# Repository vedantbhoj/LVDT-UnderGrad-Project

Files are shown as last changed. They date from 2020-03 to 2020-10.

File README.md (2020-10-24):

# LVDT-UnderGrad-Project
LVDT(Linear Variable Diffrential Transformer)

Please check out the working of this project on YouTube.

<a href="https://youtu.be/okFGslv-gCQ">Demo - Youtube Video</a>

<a href="https://github.com/vedantbhoj/LVDT-UnderGrad-Project/blob/master/PROJECT%20REPORT/PROJECT%20REPORT.pdf">Project Report</a>

Note: Cannot support this repository anymore. Thanks!!

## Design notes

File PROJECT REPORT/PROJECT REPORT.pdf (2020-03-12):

## 1.INTRODUCTION

“LVDT”

LVDT is most widely used inductive transducer for translating the linear motion into

electrical signal. Magnetic coupling between primary and secondary coils is established by

using a soft and movable iron core. In normal LVDT both the secondary coils are connected

in series opposition. However, the output voltage is zero. As the core moves up or down, the

induced voltage in one secondary coil increases while that of the other decreases. Here the

magnitude of the output voltage is in AC nature.

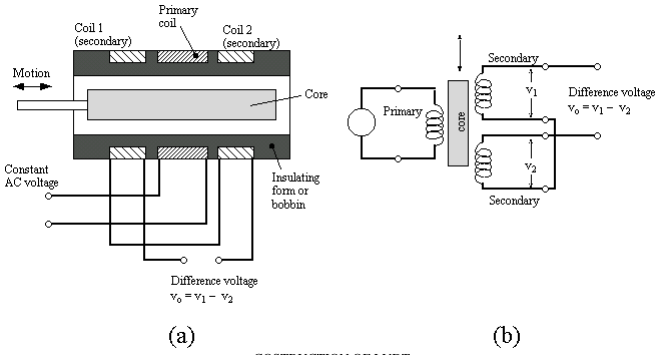
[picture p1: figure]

COSTRUCTION OF LVDT

## 2. BACKGROUND

Since the 1930s, linear variable differential transformers (LVDTs) have found widespread

application in industry for the measurement of displacement. Early development was driven by the

needs of the chemical industry to remotely measure process variables, and during World War II

development accelerated rapidly as the LVDT found use in aircraft and weapon systems. Today, the

LVDT has evolved into a highly accurate and reliable form of displacement transducer, and is

widely used in many branches of industry and science.

Since the LVDT is basically a transformer, it requires an alternating signal to excite the

primary coil and some form of electronic circuit to condition the return signal in order to extract

displacement information. Almost all such circuits in use today are designed with analog

components for both functions. While these are usually robust and cheap to produce, their design

can be challenging if accurate measurements are required. This is because both the construction of

the transducer and the presence of spurious phase shift in the return signal path contribute to non-

linear measurement error, which can be difficult to eliminate using analog techniques.

Existing Systems

One possible alternative to LVDTs is a magnetostrictive sensor. Magnetostrictive

technology might provide several possible advantages to LVDT technology in power generation

applications. First, because magnetostrictive sensors are resistant to shock, vibration and other

harsh environments, they could meet utility reliability and durability requirements.

The DC-operated LVDT maintains all the desirable characteristics of the AC-operated

LVDT, but has the simplicity of DC operation. It is comprised of an AC-operated LVDT and a

carrier generator/signal conditioning module.

## 3. BLOCK DIAGRAM

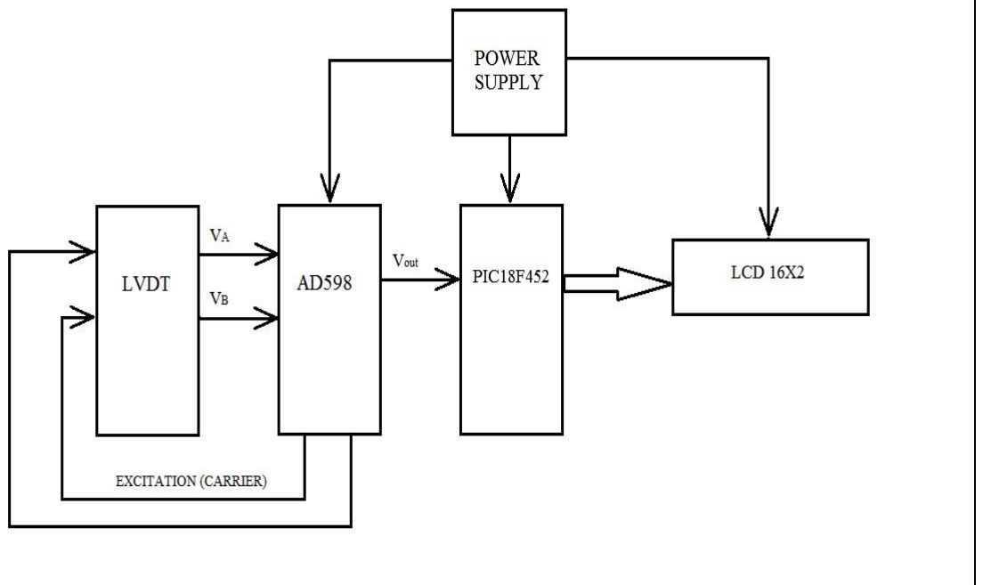
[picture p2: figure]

BLOCK DIAGRAM DESCRIPTION

### 3.1. LVDT

- This LVDT can measure distance precisely from -10 mm to 10 mm.
- For measurement of displacement micro meter screw gauge is provided.
- Primary Coil of LVDT is energized by the voltage provided by IC AD 598.
- The output from the LVDT secondaries consists of a pair of sine waves whose amplitude difference, (VA–VB), is proportional to core position.
- This output of LVDT secondaries is again given back to the IC AD598 then the IC gives proportional constant DC output Voltage.

### 3.2. AD598

The AD598 is a complete, monolithic Linear Variable Differential Transformer (LVDT)

signal conditioning subsystem. It is used in conjunction with LVDTs to convert transducer

mechanical position to a unipolar or bipolar dc voltage with a high degree of accuracy and

repeatability. All circuit functions are included on the chip. With the addition of a few external

passive components to set frequency and gain, the AD598 converts the raw LVDT secondary

output to a scaled dc signal.

The AD598 energizes the LVDT primary, senses the LVDT secondary output voltages and

produces a dc output voltage proportional to core position. The AD598 consists of a sine wave

oscillator and power amplifier to drive the primary, a decoder which determines the ratio of the

difference between the LVDT secondary voltages divided by their sum, a filter and an output

amplifier. The oscillator comprises a multi vibrator which produces a triwave output. The triwave

drives a sine shaper, which produces a low distortion sine wave whose frequency is determined by

a single capacitor. Output frequency can range from 20 Hz to 20 kHz and amplitude from 2 V rms

to 24 V rms.

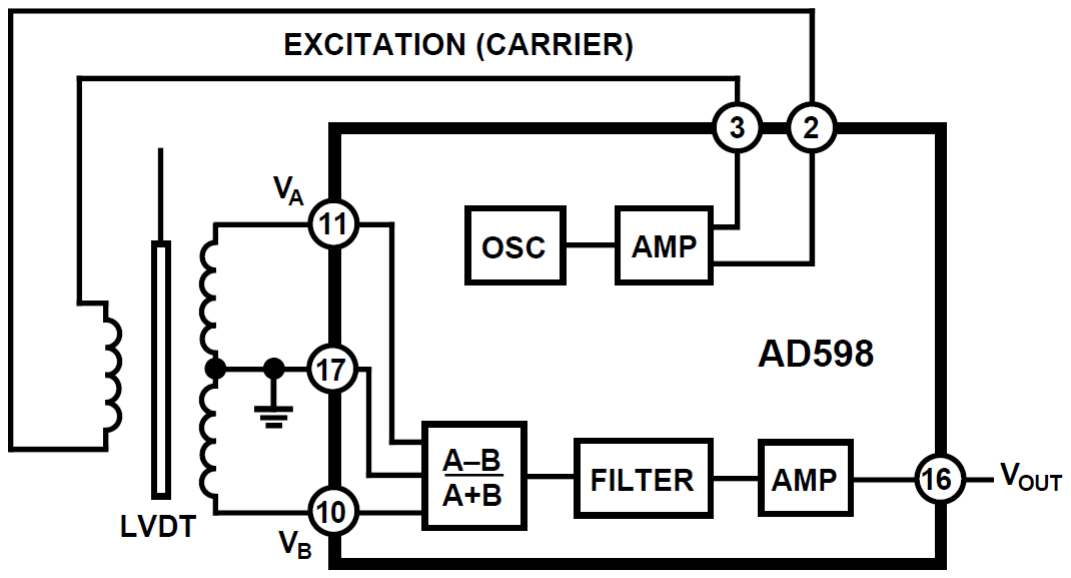
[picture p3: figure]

INTERNAL CIRCUIT OF AD598

### 3.3. Microcontroller PIC18F4520

This family offers the advantages of all PIC18 microcontrollers namely, high computational

performance at an economical price – with the addition of high endurance, Enhanced Flash

program memory. On top of these features, the PIC18F2420/2520/4420/4520 family introduces

design enhancements that make these microcontrollers a logical choice for many high performance,

power sensitive applications.

The core features of the microcontroller are as follows:

- High performance RISC CPU
- 10 bit ADC
- Operating speed: DC - 40 MHz clock input DC - 200 ns instruction cycle
- Up to 8K x 14 words of FLASH Program Memory, Up to 368 x 8 bytes of Data Memory (RAM, Up to 256 x 8 bytes of EEPROM Data Memory.
- Interrupt capability (up to 14 sources)
- Eight level deep hardware stack
- Direct, indirect and relative addressing modes
- Power-on Reset (POR)
- Programmable code protection
- Selectable oscillator options
- Low power, high speed CMOS FLASH/EEPROM technology
- Single 5V In-Circuit Serial Programming capability
- Processor read/write access to program memory
- Wide operating voltage range: 2.0V to 5.5V
- High Sink/Source Current: 25 mA
- Commercial, Industrial and Extended temperature ranges
- Low-power consumption

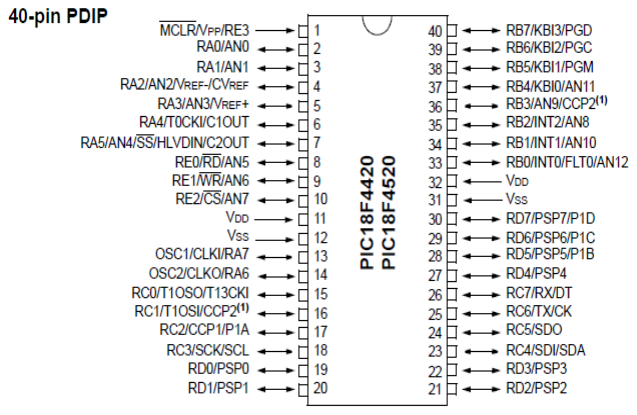
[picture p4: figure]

PIN DIAGRAM OF PIC1854520

### 3.4. DC Power Supply

For microcontroller, as well as the AD598, a regulated DC power supply is required. We

have to provide +5V to the microcontroller, while +15&-15V to the AD598. The input to the power

supply block is AC mains i.e. 230Vrms, 50Hz, 1-phase. The input AC mains are given to a step

down transformer which gives the output voltage as 36Vrms and 1A. The signal obtained is AC in

nature, hence it is given to a bridge rectifier circuit to rectify. This signal is further given to a filter

capacitor in order to reduce the ripple in the signal. This signal is then given to IC 7815 and

IC7915. This regulator IC provides DC voltage (+15V and -15V). The current provided by the

power supply unit is around 1A. This voltage and current is used for driving AD598. We have used

the Bridge IC instead of Rectifier Diodes it saves space as well as provides stability to supply. We

have used BRIDGE IC A10W.

### 3.5. LCD

Alpha numeric modules display characters, numerals, symbols and some limited graphics.

For design that has been presented, we have selected a 16*2 alphanumeric LCD. This alphanumeric

LCD has low current drain; it does not require high supply voltage. Thus looking at advantages and

availability we have chosen 16*2 alphanumeric LCD.

LCD

## 4. ELECTRONIC AND HARDWARE DESIGN ASPECT

4.1.POWER SUPPLY DESIGN

The PCB for the power supply unit is a board with the input as AC mains i.e. 230Vrms,

50Hz, 1-phase and the output as +15V and -15V DC. It is a single sided PCB with dimensions

10cm x 6cm. The width of each of the track in the PCB is 1mm. the clearance constraint set is

0.5mm.

A step down transformer is used to step down the voltage from 230Vac to 36Vac. This

voltage is further more stepped down to and converted to+15V and -15V DC using a circuit

comprising of a bridge rectifier IC, filter capacitor and the 7815 and 7915 regulator IC.

### 4.1.1 REGULATOR IC

The required output voltage is +15V and -15V. Hence we use regulator IC 7815 and IC7915

which has the following specifications:

- Output Current up to 1A
- Output Voltage of +15V and -15V
- Thermal Overload Protection
- Short Circuit Protection
- Input voltage range: 17.5 V to 30 V

A capacitor valued 2200uF is put at the input side of the regulator IC, in order to improve the

transient response and to reduce the ripples in the voltage being applied as the input; a capacitor

valued 10uF is put at the output side of the regulator IC, this is done in order to reduce the effect of

noise when the distance between load and IC is greater than 6 inches.

### 4.1.2 DESIGN OF FILTER CAPACITOR

Filters are used in order to reduce the ripple content of the voltage. This is used so that

output voltage has minimum amount of ripple content present in it.

Voltage at input of capacitor,

VIN = VO + VD + VSAFETY

=15 + 2 + 2 = 19V
WVDC = 2 x VIN = 38V
Assume ripple voltage, VR = 2V EMAX = VIN + VR/2 = 20V
EMIN = VIN – VR/2 = 18V
θ = sin⁻¹ (EMIN /EMAX ) = 64.15 90̊ ≡ 5ms
64.15 ≡ 3.56ms
T1 = time (90̊ ) + time(θ̊ ) = 8.56ms

Value of capacitor, C = IL x T1/ VR = 2140uF
The value of capacitor used is 2200uF and WVDC as 25V.

For this project we are going to use bridge rectifier IC of Fairchild Conductors A10W.

4.1.3.DESIGN OF THE STEP DOWN TRANSFORMER

To convert the input 230V to 16V and also to electrically isolate the circuit from mains, we

have to require the step down transformer.

Voltage at output of the transformer,

VO= VoREG + VDROP(IC) + VDROP(RECTIFIER)
= 32+ 2 + 2
= 36

### Turns ratio = VI N / VO

= 230 / 36
=6.38:1
=7:1

### 4.2 LVDT Signal Conditioning

The AD598 contains a low distortion sine wave oscillator to drive the LVDT primary. The

LVDT secondary output consists of two sine waves that drive the AD598 directly. The AD598

operates upon the two signals, dividing their difference by their sum, producing a scaled unipolar or

bipolar dc output, following circuit arrangement was used:

### Frequency range: 20Hz to 20 KHz for AD598

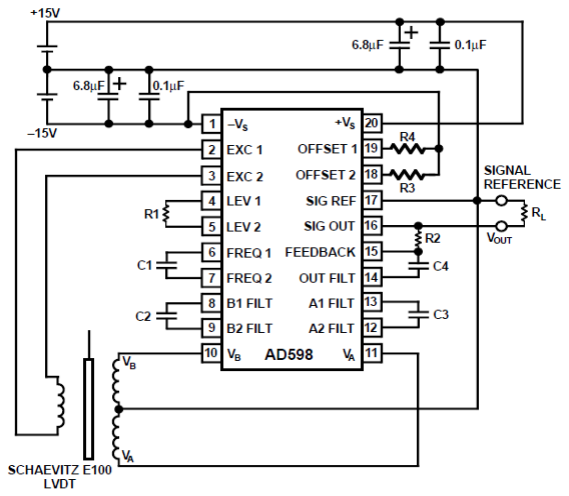
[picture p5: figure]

INTERFACING DIAGRAM OF AD598 WITH LVDT

### 4.2.1 Selection of components for AD598:

- For mechanical BW. Assume f-SUBSYSTEM = 250 Hz.
- Select minimum LVDT excitation frequency, approximately 10 X f-SUBSYSTEM. Excitation frequency = 2.5 kHz.
- Determine VA+VB = 4.55V rms.

VTR = VPRI/VSEC
For VSEC = 0.85 V rms , VPRI = 3 V rms. VTR = 3.5
- The AD598 signal input, VSEC, should be in the range of 1 V rms to 3.5 V rms for maximum AD598 linearity and minimum noise susceptibility. Select VSEC = 2 V rms. Therefore,

LVDT excitation voltage VEXC should be: VEXC = VSEC × VTR = 2 × 3.5 = 7 V rms

As we Vexc is 7Vrms, so R1=4 k ohm

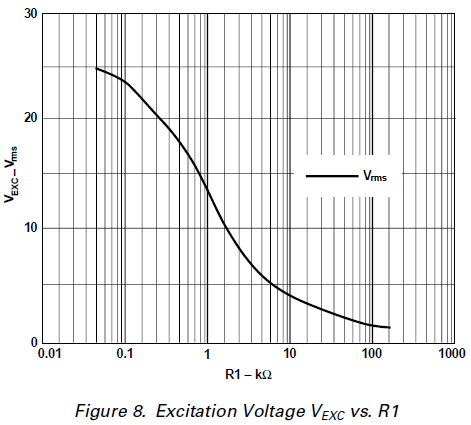
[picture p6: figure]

- Select the value of the amplitude determining component R1 as shown by the curve.

- Select excitation frequency determining component C1. C1 = 35 uF Hz/f EXCITATION C1 = 35 uF Hz/2.5KHz
C1=15nf
- C2, C3 and C4 are a function of the desired bandwidth of the AD598 position measurement Subsystem. They should be nominally equal values.
C2 = C3 = C4 = 10–4 Farad Hz/f SUBSYSTEM (Hz) If the desired system bandwidth is 250 Hz, then
C2 = C3 = C4 = 10–4 Farad Hz/250 Hz = 0.4 uF
In order to Compute R2, which sets the AD598 gain or full scale output range, several pieces of information are needed:
LVDT sensitivity(S) Full-scale core displacement(d), Ratio of manufacturer recommended
primary drive level, | R2 = VOUT × (VA +VB ) (S ×VPRI × 500 µA × d)

For VOUT = 20 V full-scale range (+-10 V) and d = 0.7874 inch full-scale displacement (+-0.393 inch),

- R3 and R4 for voltage offset adjustment. For no offset adjustment R3 and R4 should be open. Set VOS = 500mV

Since a positive offset is desired, let R4 be open circuit. solving for R3
R3 = 1.2 × R2 - 5kohm = 76.2kohm VOS

4.3.POWER BUDGET

COMPONENTS | Current | Voltage | POWER(Watt)
PIC18F4520 | 300 mA | 5 V | 1.5 W
LCD | 1.2 mA | 5 V | 0.006 W
AD598 | 12 mA | 30 V | 0.360 W
TOTAL POWER | | | 1.866 W

Power required = 1.866 W

4.4.MICROCONTROLLER BOARD

PIC SELECTION

Parameter | PIC16F688 | PIC16F877 | PIC18F4520
Pin Count | 14 | 28/40 | 28/40/44
Operating vtg | 2V – 5.5V | 2V – 5.5V | 2V – 5.5V
Operating freq | 0 to 20MHz | 0 to 20MHz | 0 to 40MHz
Inbuilt ADC | 8 | 8 | 13
ADC bits | 10 | 10 | 10
No of timers(8/16) | 1/1 | 3/0 | 1/3
Prog Memory | 4K | 8K | 32K
Data memory | 256(SRAM),256(E EPROM) | 368(SRAM),256(EEP ROM) | 1536(SRAM),256(E EPROM)

From this comparison we are selecting the PIC 18F4520 as our microcontroller as it is

satisfying our project requirements such as high pin count, data memory.

RESET CIRCUIT

We are connecting a circuit to the MCLR (pin1) of the microcontroller (18f4520).The

resistor value is taken from the datasheet i.e. of 1Kohm. The PIC has an active low reset, thus when

push button is pressed, the path for ground connection gets completed and a low signal is given to

the microcontroller.

CRYSTAL CIRCUIT

Here we are connecting two capacitors which are basically of values 15pF each. In other

words to give a pure square wave to the microcontroller. Basic rule for placing the crystal on the

board is that it should be as close as possible to avoid any interference in the clock.

The microcontroller board gets 5Vdc input from the power supply board or battery. The

reset pin on the microcontroller is an active low pin; hence the microcontroller will be in reset state

if connected to ground. Hence it is connected to Vcc through a 1k resistor. A reset switch is

connected to the MCLR pin. When the reset switch is pushed, the MCLR pin gets connected to

ground and thus gets reset.

## 5. SOFTWARE ASPECTS

a) PROTEUS: This software is used for simulations of circuits. This gives us ability to

simulate controller based circuits by downloading hex files to it

b) ALTIUM 10: Altium software is used for designing of PCB. First of all we have to

make schematic and then we have to place components logically on PCB Board To make

the tracks.

c) MIKRO C: For programming of Microcontroller we used ‘MIKRO C’ Software it has

inbuilt function of various commands that are commonly used.

### 5.1 ALGORITHM

1) START.
2) Initialize the PORT A as input.
3) Initialize the PORT D as output.
4) Initialize the LCD.
5) Initialize the ADC.
6) Display “Project Name-LVDT” string.
7) Display “3119, 3122, 3123” string

Display “DISPLACEMENT”.

8) Read RA0. (Get 10 bit value form ADC)
9) Convert the values of ADC into mV.
10) Display the values obtained from ADC on LCD.
11) Again go to step 8 and execute this loop for infinite times.
12) STOP.

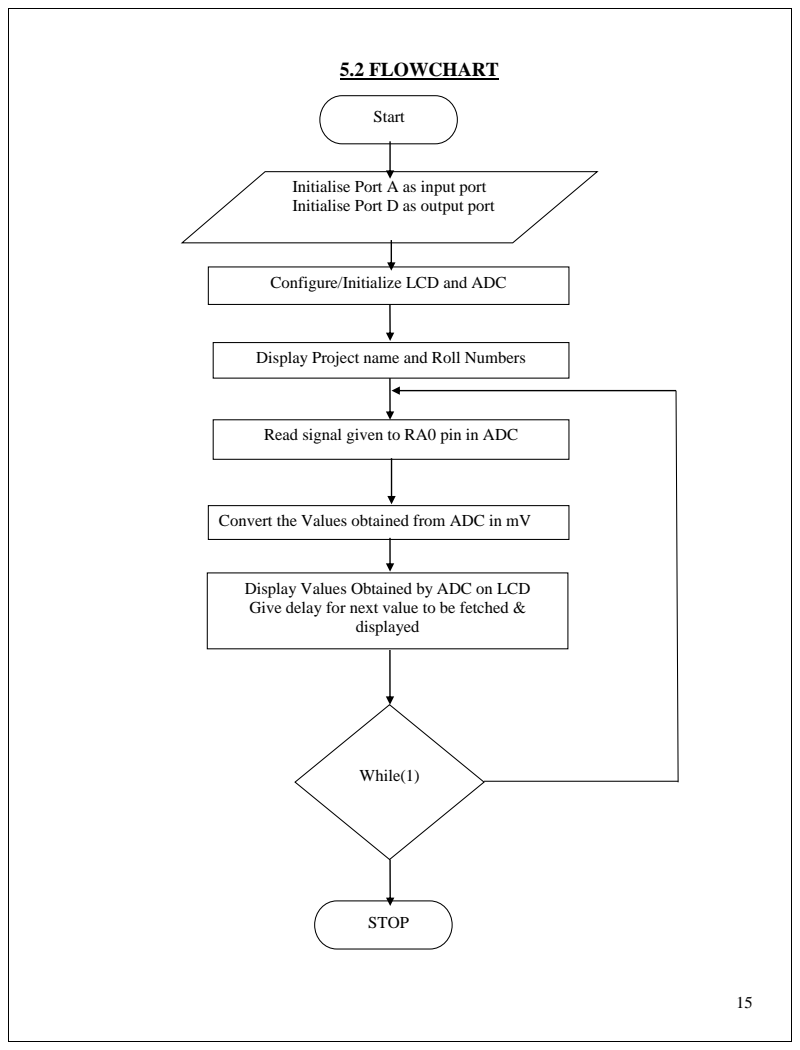
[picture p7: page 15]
5.2 FLOWCHART; Start; displayed; While(1); STOP

Initialise Port A as input port
Initialise Port D as output port

Configure/Initialize LCD and ADC

Display Project name and Roll Numbers

Read signal given to RA0 pin in ADC

Convert the Values obtained from ADC in mV

Display Values Obtained by ADC on LCD
Give delay for next value to be fetched &

## 6.Circuit design

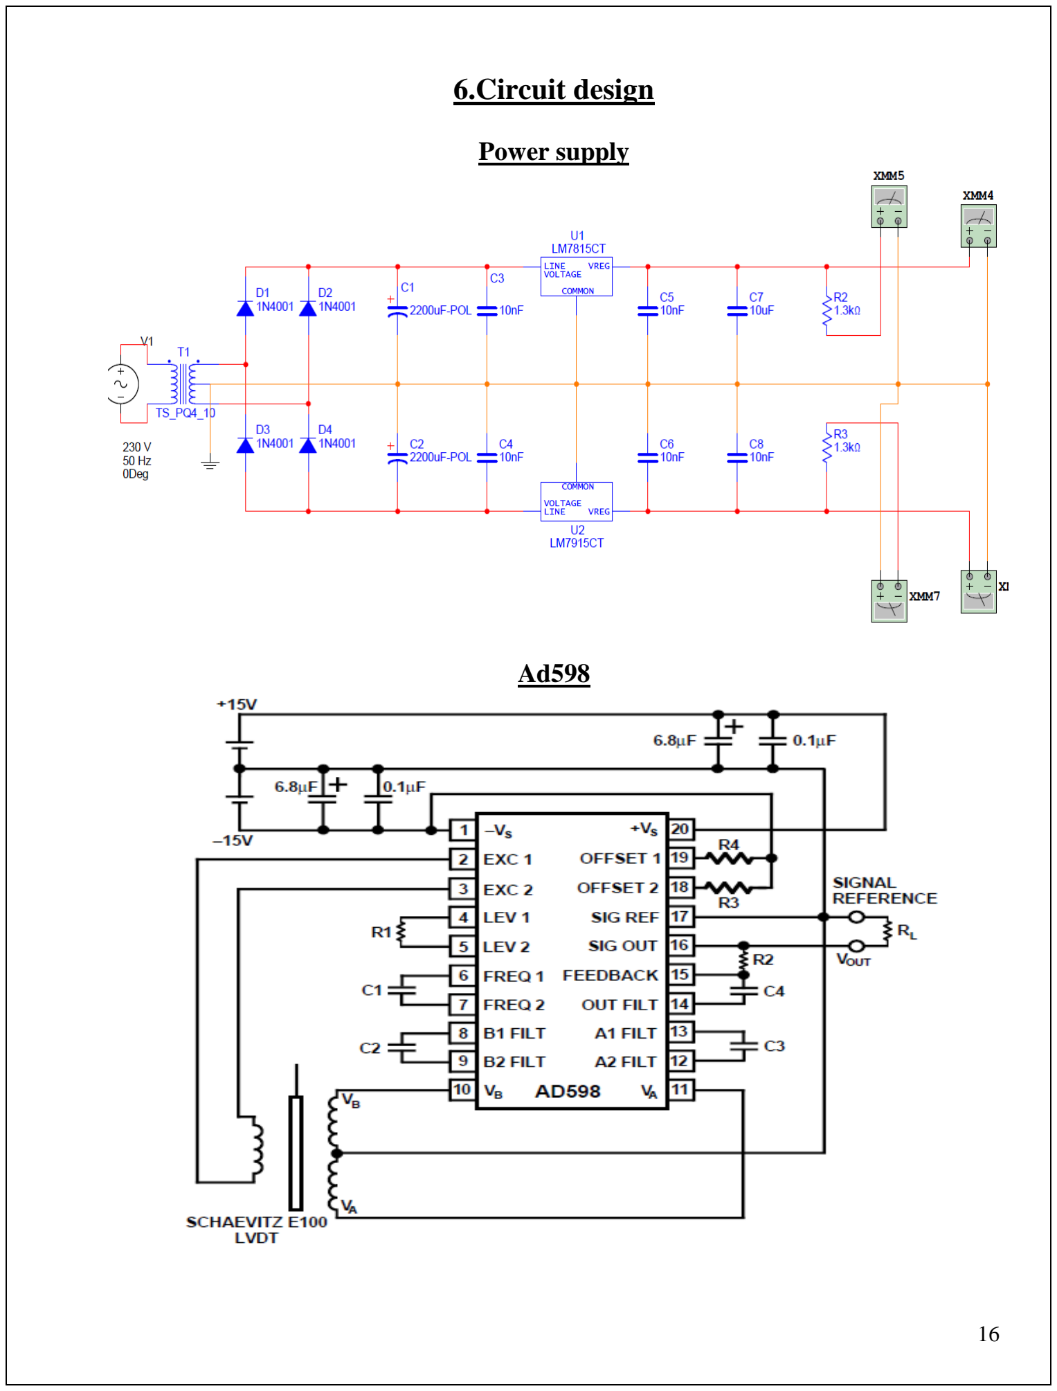
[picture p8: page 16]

Power supply

Ad598

PIC 18F4520

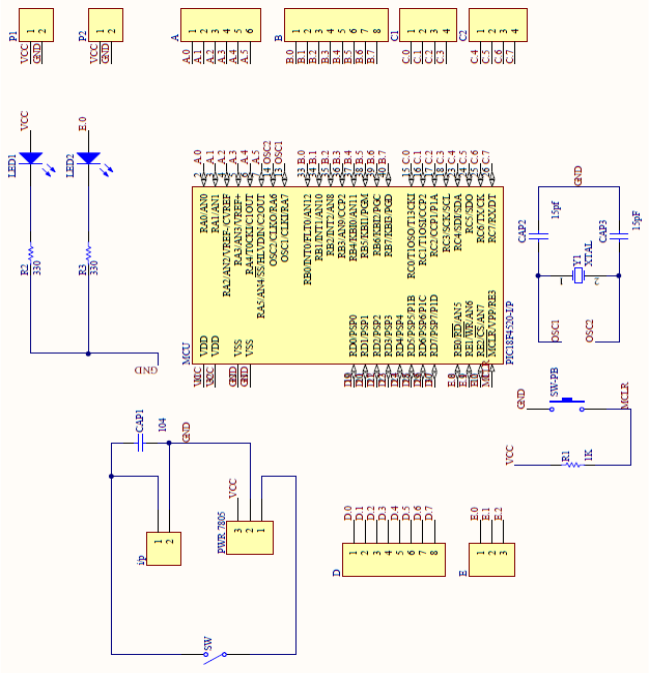
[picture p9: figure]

## 7. SIMULATION RESULT

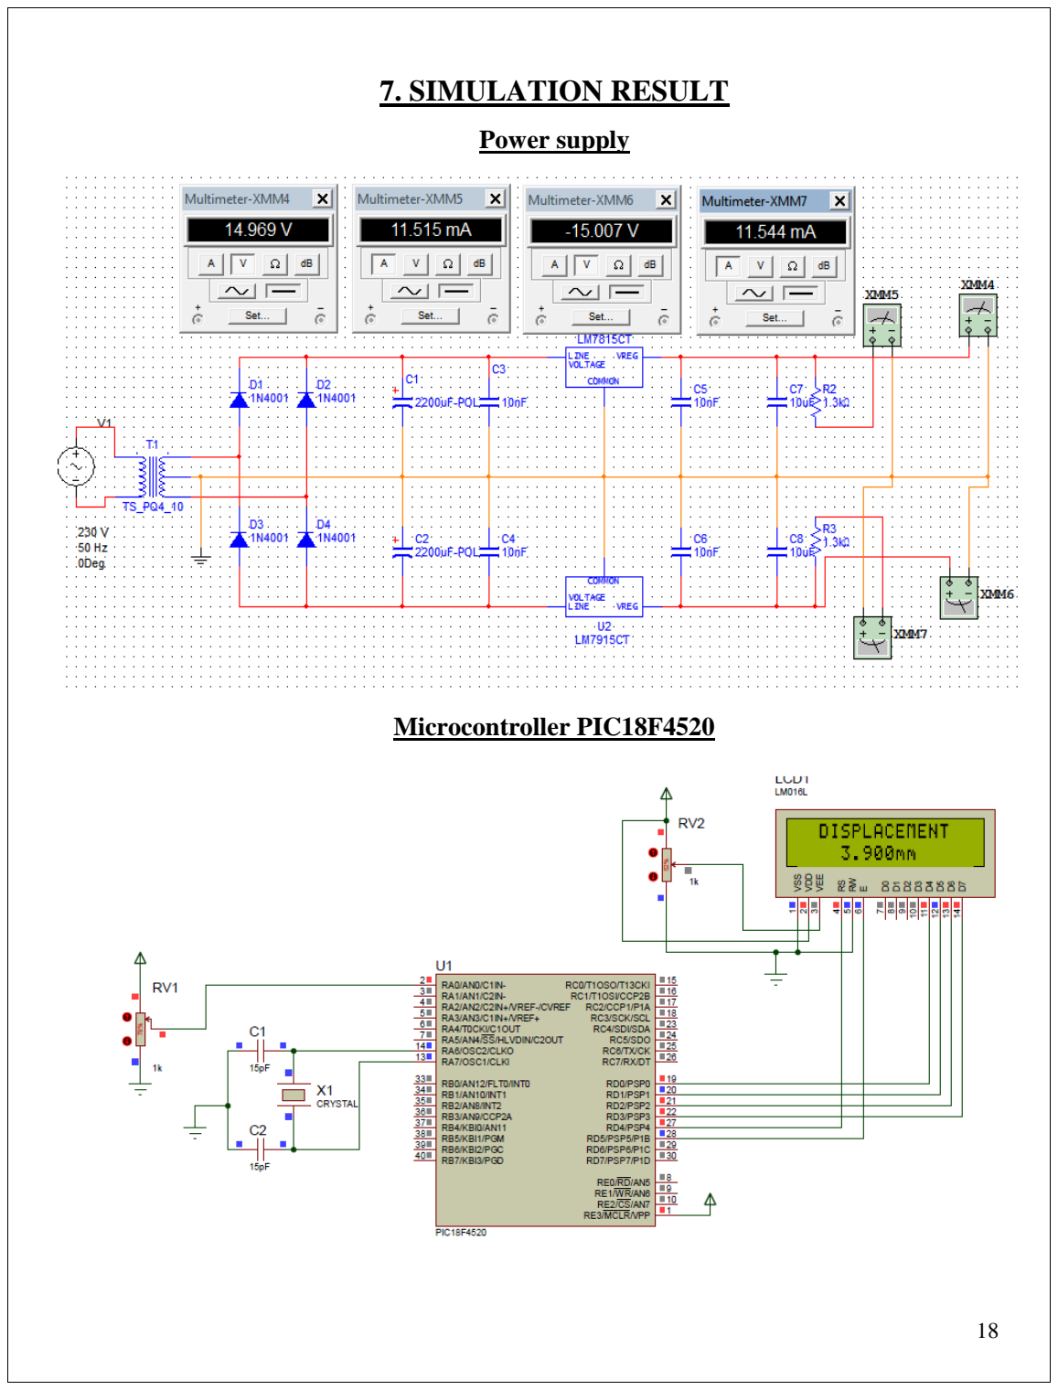
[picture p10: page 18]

Power supply

Microcontroller PIC18F4520

## 8.PCB Design & layouts

The most important requirement of this project was to build a PCB with minimum weight

and size. A proper PCB with a drilled board. Proper PCB removes a lot of material from board, and

the weight is reduced. Designing method is as followed by using ALTIUM PCB Designing

Software.

1. Decide proper Circuit Diagram of Both Microcontroller and Power Supply Circuit
2. Actual Placement of components on ALTIUM.
3. Connecting Tracks with proper Width using Proper rules and angles
4. Create Proper Print required for PCB Designing
5. Design PCB using Proper Solutions.
6. Verifying Proper Track widths and Placing of Components at proper Places
7. Verification of Proper Supply and Circuit.

Three PCBs are designed in this project. The PIC18F4520 PCB, the AD598 signal

conditioning PCB, and power supply PCB. All PCBs are constructed on simple PCB, and

interconnection of PCB’s was done by using single stranded wires.

PCB Dimensions

Sr. No | PCB NAME | Length | Breadth | Clearance | Track Width
1) | POWER SUPPLY | 100 | 60 | 0.5 mm | 1 mm
2) | AD 598 PCB | 85 | 80 | 0.5 mm | 1 mm
3) | PIC 18F4520 | 95 | 91 | 0.5 mm | 0.8mm Vcc=1 mm

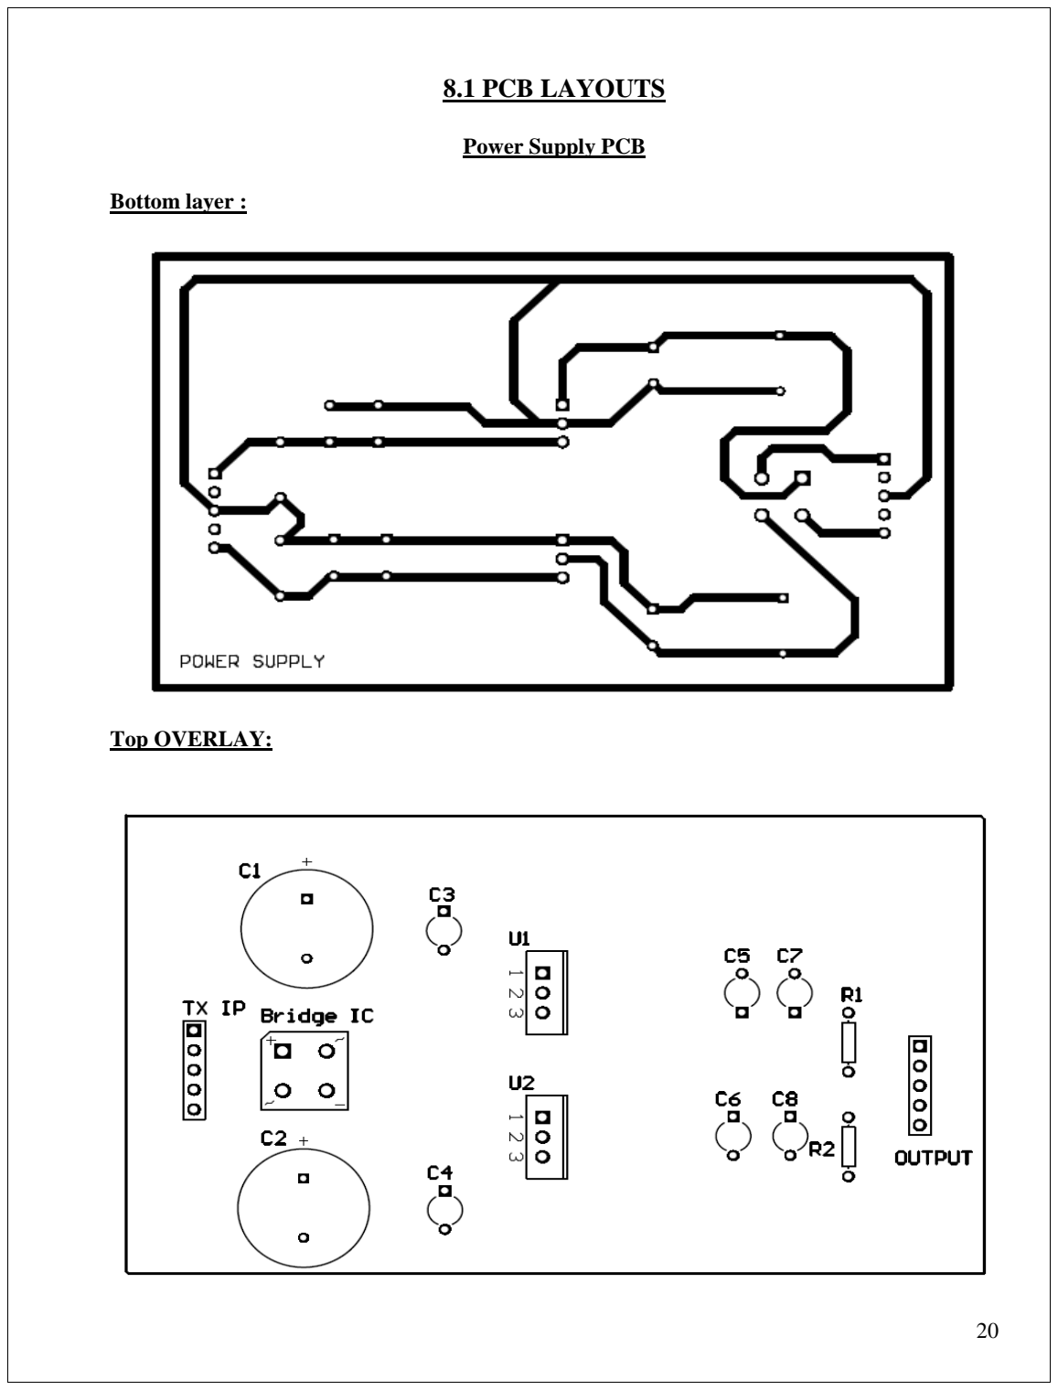
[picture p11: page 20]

### 8.1 PCB LAYOUTS

Power Supply PCB

Bottom layer :

Top OVERLAY:

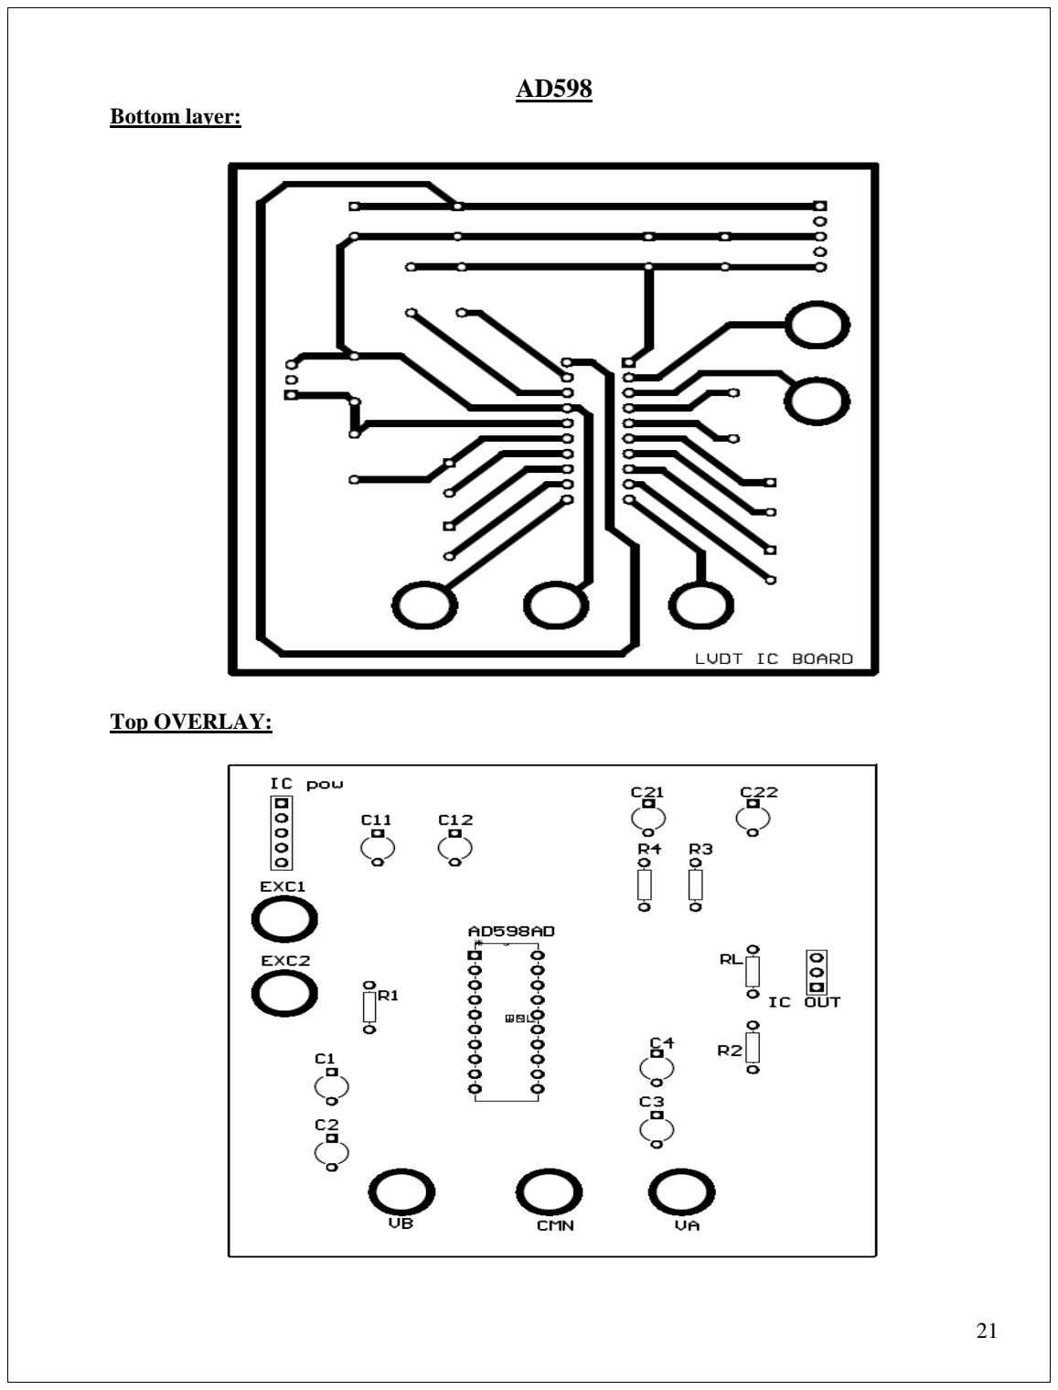
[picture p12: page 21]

AD598
Bottom layer:

Top OVERLAY:

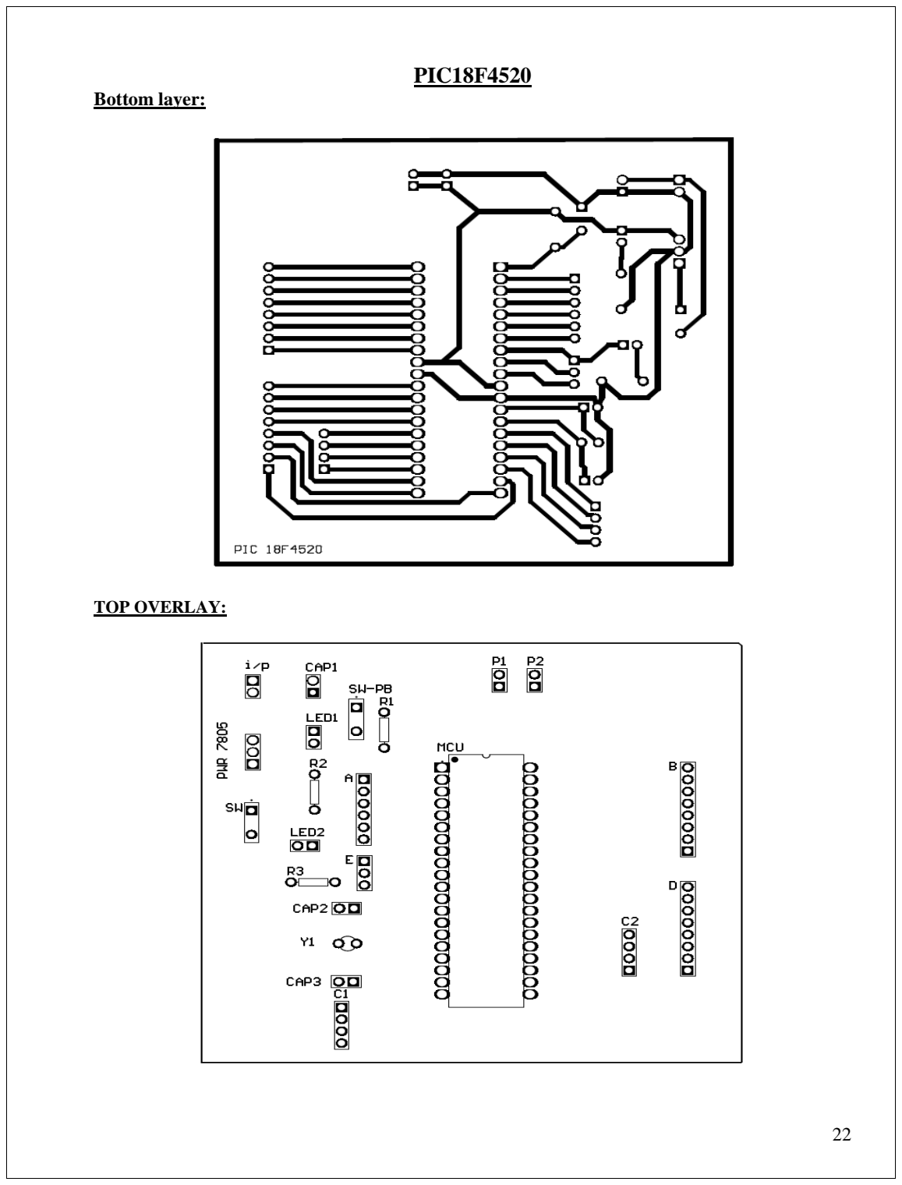
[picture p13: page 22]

PIC18F4520
Bottom layer:

TOP OVERLAY:

## 9. TESTING OF MODULES

Continuity of the tracks of PCBs was checked both before and after soldering the

components. The components were soldered only after ensuring correctness of the PCB tracks.

Then all supply/biasing voltages were checked.

Sr. No. | TEST POINT | VOLTAGE
1. | MCLR | +5V
2. | Pin 11,32 of PIC18f452 & Pin 2 of LCD | +5V
3. | Pin 12,31 of PIC18f452 & Pin 1,5,7,8,9,10 of LCD | 0V
4. | Input to 7805 | 15V
5. | Transformer primary winding | ≅ 230V A.C.
6. | Transformer secondary winding (18- 0 -18 V) | ≅ 36V A.C.
7. | Power supply output | + 15V D.C.
8. | Input to AD598 | + 15V D.C.
9. | Output of AD598 | + 10V D.C.
10. | Frequency between pin no 6 &7 of AD598 | 2.5 KHz

## 10.CABINATE DESIGN AND ASSEMBLY

The cabinet is an acrylic enclosure of dimensions 26*16 cm while the height being 8 cm.

The acrylic sheet that we selected is a 3 mm thick sheet. The enclosure formation required cutting,

drilling and using adhesives the box is made. The cabinet design requires utmost importance to be

given for the spacing and the where to place each component. Apart from this it also requires

dimensional analysis of each component.

Our Cabinet design specifications are as follows:

Length: 26 cm

Width: 16 cm

Height: 8 cm

Thickness of the acrylic sheet: 3mm

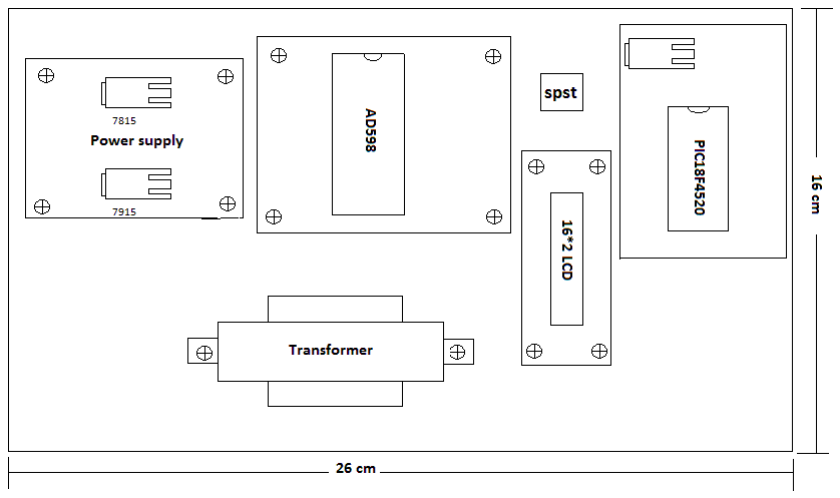
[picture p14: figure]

## 11.BILL OF MATERIALS

SR.NO | COMPONENTS | SPECIFICATIONS | QUANTITY | COST
1 | RESISTOR
| 10 KΩ pot | 1 | 1/-
| 1 KΩ | 1 | 1/-
| 330 Ω | 2 | 1/-
| 4.2 KΩ | 2 | 1/-
| 76.2 KΩ | 1 | 1/-
| 63.5 KΩ | 1 | 1/-
2 | CAPACITORS
| 2200uF | POLAR 25V | 2 | 40/-
| 10nF | Ceramic | 4 | 4/-
| 10uF | POLAR | 2 | 4/-
| 0.1uF | Ceramic | 2 | 2/-
| 6.8uF | POLAR | 2 | 2/-
| 0.4uF | Mylar Cap | 3 | 3/-
| 15nF | Box type | 1 | 1/-
| 15pF | Ceramic | 2 | 2/-
3 | IC 7805 | Vin= 7-20V Vo= 5V Io= 5mA – 1A
1 | 10/-
4 | IC 7815 | Vin= 17.5 – 30 V Vo= 15V Io= 5mA – 1A
1 | 10/-
5 | IC 7915 | Vin= -18 to -30 V Vo= -15V Io= 5mA – 1A
1 | 10/-
6 | AD598 | DC Output Proportional to Position 20 Hz to 20 kHz Frequency Range Linearity: 0.05% of FS max Output Voltage: 611 V min
1 | 3800/-
7 | PIC18F4520 | Enhanced Flash Microcontroller with 10-Bit A/D, 32K Flash, 40-Pin PDIP
1 | 220/-

8 | Battery | 9V General Purpose Battery | 1 | 15/-
9 | Transformer | Step Down Centre tap 18-0-18 V, 1A | 1 | 140/
10 | Diode bridge | IC A10W | 1 | 15/-
11 | LED | Red Colour | 2 | 2/-
12 | SW-PB | Push Button | 1 | 4/-
13 | On/off switch | SPST | 1 | 5/-
14 | Crystal (XTAL) | 10 MHz | 1 | 12/-
15 | PCB fabrication | PIC PCB: 95mm x 91mm Power Supply:100mm x 60mm AD 598 PCB:80mm x 85mm | 3 | 400/-
16 | ZIF socket | (40pin+20pin) | 2 | 90/-
17 | LCD | 16X2 alphanumeric LCD | 1 | 150/-
18 | Enclosure | Acrylic Sheet Casing | 1 | 500/-
19 | LVDT | -10 to 10 mm displacement | 1 | 8000/-
| | Total | | 13512/-

## 12.REFERENCES

1) PIC Microcontroller and Embedded System (Mazidi)
2) Advanced PIC Microcontroller Projects in C – (Dogan Ibrahim)
3) Analog devices AD598 datasheet.
4) www.analog.com/en/other-products/lvdt-sensor-amplifiers/ad598/products/product.html
5) PIC 18F4520 datasheet
6) http://www.microchip.com/PIC18F4520
7) LM 7805, 7815 & 7915 datasheets.
8) http://www.fairchildsemi.com
9) http://www.meas-spec.com/downloads/Principles_of_the_LVDT.pdf
10) http://www.macrosensors.com/lvdt_tutorial.html
11) http://www.sensorsmag.com/sensors/position-presence-proximity/modern-lvdts-new-

applications-air-ground-and-sea-7508

## 13. PROJECT PHOTO

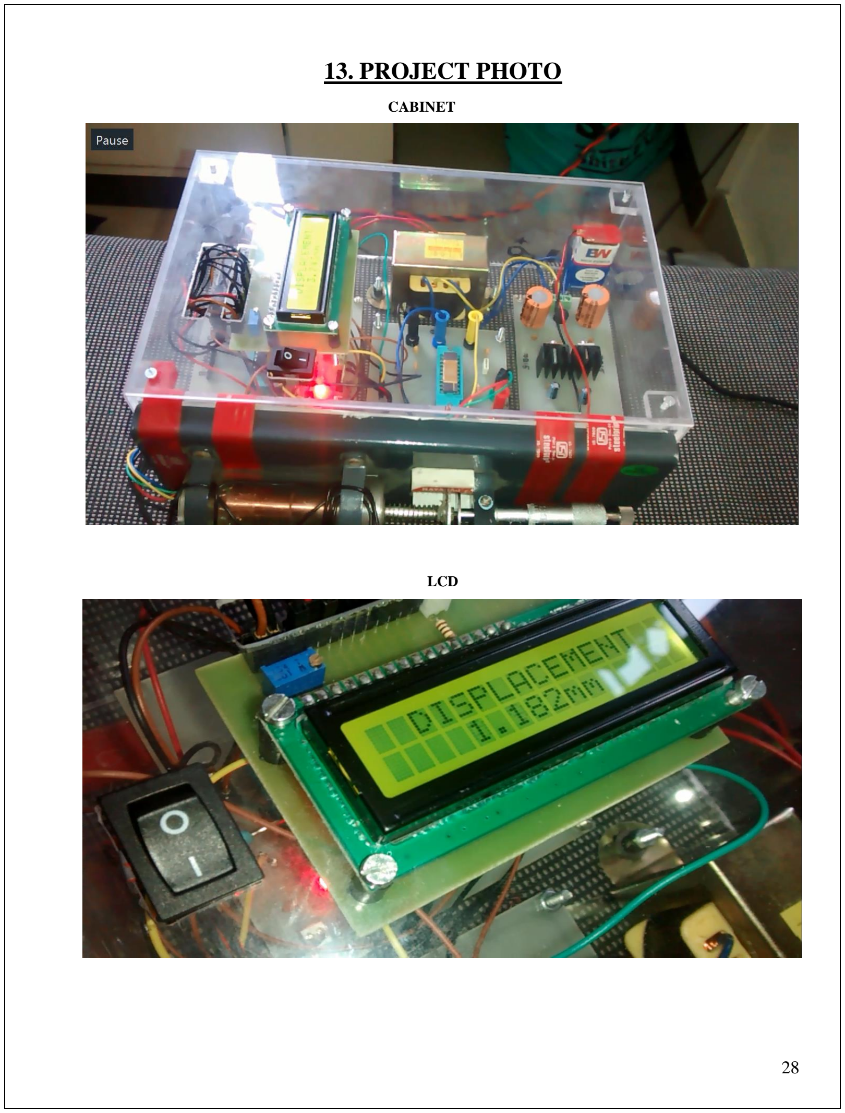
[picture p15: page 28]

CABINET

LCD

LVDT

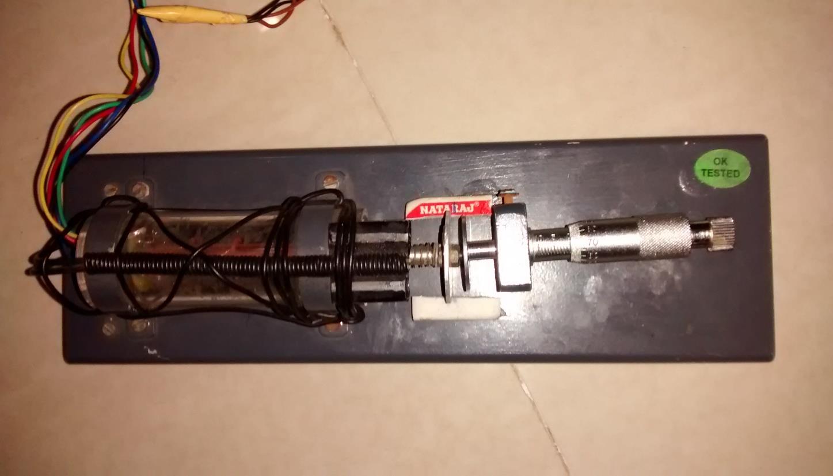
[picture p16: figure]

LINEARITY OF LVDT

0

0.474

1.001

1.524

2.067

2.639

3.152

3.7

4.281

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
0 | 0.5 | 1 | 1.5 | 2 | 2.5 | 3 | 3.5 | 4 | 4.5 | 5

### Distance(mm) v/s Voltage(V)

### 13. CONCLUSION

Through this project development we not only learnt the ensemble procedures of making a

project but also imbibed various design aspects namely soldering, debugging and testing. At the

end of the project we have also got an analytic view so as to implement our project at various facets

of our life and also to see the shortcomings of the project. We have also learnt to have an outlook to

view the project as a “product” and its development in the mere future.

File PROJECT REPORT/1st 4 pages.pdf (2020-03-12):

BansilalRamnathAgarwal Charitable Trust’s

## Vishwakarma Institute of Information Technology

## (Department of Electronics & Telecommunication)

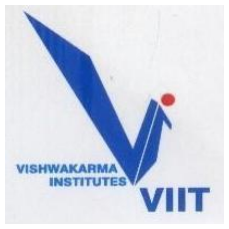
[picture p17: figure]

A
Project entitled

## “Linear Variable Differential Transformer (LVDT)”

Submitted by

Vedant Bhoj | (T80393027)
Faizan Bute | (T80393035)
Harsh Chaturvedi | (T80393074)

Mini Project & Seminar

T.E. Electronics & Tele-Communication

of

University of Pune

Under the supervision of

Prof. V. B. Ambhore

(Project Guide)

Year 2013 – 2014

BansilalRamnathAgarwal Charitable Trust’s

## Vishwakarma Institute of Information Technology

## (Department of Electronics & Telecommunication)

## CERTIFICATE

This is to certify that the project “LVDT” has been successfully completed by

Vedant Bhoj
Faizan Bute
Harsh Chaturvedi

It is an original work done by the students and has not been submitted previously by any

other student/students for the award of any other degree of same or other university.

The work is done, on the basis of the work allotted to these students, based on various

Project ideas presented by them.

This project report is being submitted as a part of the subject Mini Project and Seminar at

T.E.-E&TC.

(Prof. Vishal B. Ambhore ) | (Prof. P. D. Khandekar)
Project Guide | H.O.D- E& TC

## ACKNOWLEDGEMENT

The Success of any project is never limited to the individual undertaking the project. There

are some personalities involved whose role is very vital for successful completion of a project.

We take this opportunity to extend our sincere thanks and gratitude them. We wish to

thanks Prof.V.B.Ambhore and Prof. Dr. R.B.Ghongade who guided us time to time during the

project. We also thank to our H.O.D. Prof.P.D.Khandekar.

At last we are thankful to all teachers and other staff members for their support and help in

making this project come true.

INDEX

Sr. No | Contents | Page No.
1. | INTRODUCTION | | 1
2. | BACKGROUND | | 2
3. | BLOCK DIAGRAM | | 3
4. | ELECTRONIC AND HARDWARE DESIGN ASPECTS | | 8
5. | SOFTWARE ASPECTS | | 14
6. | CIRCUIT DESIGN | | 16
7. | SIMULATION RESULTS | | 18
8. | PCB LAYOUT | | 19
9. | TESTING OF MODULES | | 23
10. | CABINET DESIGN AND ASSEMBLY | | 24
11. | BILL OF MATERIALS | | 25
12. | REFERENCES | | 27
13. | PROJECT PHOTO | | 28
14. | CONCLUSINON | | 30
15. | DATA SHEETS | | 31

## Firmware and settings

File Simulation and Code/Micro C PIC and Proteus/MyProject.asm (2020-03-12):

_main:

;MyProject.c,26 :: 		void main() {
;MyProject.c,29 :: 		TRISA=0xFF;
	MOVLW       255
	MOVWF       TRISA+0 
;MyProject.c,32 :: 		ADCON0=0x01;
	MOVLW       1
	MOVWF       ADCON0+0 
;MyProject.c,33 :: 		ADCON1=0x0E;
	MOVLW       14
	MOVWF       ADCON1+0 
;MyProject.c,37 :: 		Lcd_Init();                        // Initialize LCD
	CALL        _Lcd_Init+0, 0
;MyProject.c,39 :: 		Lcd_Cmd(_LCD_CLEAR);               // Clear display
	MOVLW       1
	MOVWF       FARG_Lcd_Cmd_out_char+0 
	CALL        _Lcd_Cmd+0, 0
;MyProject.c,40 :: 		Lcd_Cmd(_LCD_CURSOR_OFF);          // Cursor off
	MOVLW       12
	MOVWF       FARG_Lcd_Cmd_out_char+0 
	CALL        _Lcd_Cmd+0, 0
;MyProject.c,41 :: 		LCD_Out(1,3,"PROJECT NAME");
	MOVLW       1
	MOVWF       FARG_Lcd_Out_row+0 
	MOVLW       3
	MOVWF       FARG_Lcd_Out_column+0 
	MOVLW       ?lstr1_MyProject+0
	MOVWF       FARG_Lcd_Out_text+0 
	MOVLW       hi_addr(?lstr1_MyProject+0)
	MOVWF       FARG_Lcd_Out_text+1 
	CALL        _Lcd_Out+0, 0
;MyProject.c,42 :: 		LCD_Out(2,5,"--LVDT--");
	MOVLW       2
	MOVWF       FARG_Lcd_Out_row+0 
	MOVLW       5
	MOVWF       FARG_Lcd_Out_column+0 
	MOVLW       ?lstr2_MyProject+0
	MOVWF       FARG_Lcd_Out_text+0 
	MOVLW       hi_addr(?lstr2_MyProject+0)
	MOVWF       FARG_Lcd_Out_text+1 
	CALL        _Lcd_Out+0, 0
;MyProject.c,43 :: 		Delay_ms(2000);
	MOVLW       26
	MOVWF       R11, 0
	MOVLW       94
	MOVWF       R12, 0
	MOVLW       110
	MOVWF       R13, 0
L_main0:
	DECFSZ      R13, 1, 1
	BRA         L_main0
	DECFSZ      R12, 1, 1
	BRA         L_main0
	DECFSZ      R11, 1, 1
	BRA         L_main0
	NOP
;MyProject.c,44 :: 		Lcd_Cmd(_LCD_CLEAR);
	MOVLW       1
	MOVWF       FARG_Lcd_Cmd_out_char+0 
	CALL        _Lcd_Cmd+0, 0
;MyProject.c,45 :: 		LCD_Out(1,8,"BY");
	MOVLW       1
	MOVWF       FARG_Lcd_Out_row+0 
	MOVLW       8
	MOVWF       FARG_Lcd_Out_column+0 
	MOVLW       ?lstr3_MyProject+0
	MOVWF       FARG_Lcd_Out_text+0 
	MOVLW       hi_addr(?lstr3_MyProject+0)
	MOVWF       FARG_Lcd_Out_text+1 
	CALL        _Lcd_Out+0, 0
;MyProject.c,46 :: 		LCD_Out(2,1,"3119  3122  3123");
	MOVLW       2
	MOVWF       FARG_Lcd_Out_row+0 
	MOVLW       1
	MOVWF       FARG_Lcd_Out_column+0 
	MOVLW       ?lstr4_MyProject+0
	MOVWF       FARG_Lcd_Out_text+0 
	MOVLW       hi_addr(?lstr4_MyProject+0)
	MOVWF       FARG_Lcd_Out_text+1 
	CALL        _Lcd_Out+0, 0
;MyProject.c,47 :: 		Delay_ms(2000);
	MOVLW       26
	MOVWF       R11, 0
	MOVLW       94
	MOVWF       R12, 0
	MOVLW       110
	MOVWF       R13, 0
L_main1:
	DECFSZ      R13, 1, 1
	BRA         L_main1
	DECFSZ      R12, 1, 1
	BRA         L_main1
	DECFSZ      R11, 1, 1
	BRA         L_main1
	NOP
;MyProject.c,49 :: 		do {
L_main2:
;MyProject.c,50 :: 		temp = ADC_Read(0);   // Get 10-bit results of AD conversion
	CLRF        FARG_ADC_Read_channel+0 
	CALL        _ADC_Read+0, 0
	MOVF        R0, 0 
	MOVWF       _temp+0 
	MOVF        R1, 0 
	MOVWF       _temp+1 
	MOVLW       0
	MOVWF       _temp+2 
	MOVWF       _temp+3 
;MyProject.c,51 :: 		temp=temp*5000/1023;   //Convert ADC value to mV
	MOVF        _temp+0, 0 
	MOVWF       R0 
	MOVF        _temp+1, 0 
	MOVWF       R1 
	MOVF        _temp+2, 0 
	MOVWF       R2 
	MOVF        _temp+3, 0 
	MOVWF       R3 
	MOVLW       136
	MOVWF       R4 
	MOVLW       19
	MOVWF       R5 
	MOVLW       0
	MOVWF       R6 
	MOVWF       R7 
	CALL        _Mul_32x32_U+0, 0
	MOVLW       255
	MOVWF       R4 
	MOVLW       3
	MOVWF       R5 
	MOVLW       0
	MOVWF       R6 
	MOVWF       R7 
	CALL        _Div_32x32_U+0, 0
	MOVF        R0, 0 
	MOVWF       _temp+0 
	MOVF        R1, 0 
	MOVWF       _temp+1 
	MOVF        R2, 0 
	MOVWF       _temp+2 
	MOVF        R3, 0 
	MOVWF       _temp+3 
;MyProject.c,55 :: 		digit[0]=(temp/1000)+48;
	MOVLW       232
	MOVWF       R4 
	MOVLW       3
	MOVWF       R5 
	MOVLW       0
	MOVWF       R6 
	MOVWF       R7 
	CALL        _Div_32x32_U+0, 0
	MOVLW       48
	ADDWF       R0, 0 
	MOVWF       _digit+0 
;MyProject.c,56 :: 		digit[2]=((temp%1000)/100)+48;
	MOVLW       232
	MOVWF       R4 
	MOVLW       3
	MOVWF       R5 
	MOVLW       0
	MOVWF       R6 
	MOVWF       R7 
	MOVF        _temp+0, 0 
	MOVWF       R0 
	MOVF        _temp+1, 0 
	MOVWF       R1 
	MOVF        _temp+2, 0 
	MOVWF       R2 
	MOVF        _temp+3, 0 
	MOVWF       R3 
	CALL        _Div_32x32_U+0, 0
	MOVF        R8, 0 
	MOVWF       R0 
	MOVF        R9, 0 
	MOVWF       R1 
	MOVF        R10, 0 
	MOVWF       R2 
	MOVF        R11, 0 
	MOVWF       R3 
	MOVF        R0, 0 
	MOVWF       FLOC__main+0 
	MOVF        R1, 0 
	MOVWF       FLOC__main+1 
	MOVF        R2, 0 
	MOVWF       FLOC__main+2 
	MOVF        R3, 0 
	MOVWF       FLOC__main+3 
	MOVLW       100
	MOVWF       R4 
	MOVLW       0
	MOVWF       R5 
	MOVWF       R6 
	MOVWF       R7 
	MOVF        FLOC__main+0, 0 
	MOVWF       R0 
	MOVF        FLOC__main+1, 0 
	MOVWF       R1 
	MOVF        FLOC__main+2, 0 
	MOVWF       R2 
	MOVF        FLOC__main+3, 0 
	MOVWF       R3 
	CALL        _Div_32x32_U+0, 0
	MOVLW       48
	ADDWF       R0, 0 
	MOVWF       _digit+2 
;MyProject.c,57 :: 		digit[3]=(((temp%1000)%100)/10)+48;
	MOVLW       100
	MOVWF       R4 
	MOVLW       0
	MOVWF       R5 
	MOVWF       R6 
	MOVWF       R7 
	MOVF        FLOC__main+0, 0 
	MOVWF       R0 
	MOVF        FLOC__main+1, 0 
	MOVWF       R1 
	MOVF        FLOC__main+2, 0 
	MOVWF       R2 
	MOVF        FLOC__main+3, 0 
	MOVWF       R3 
	CALL        _Div_32x32_U+0, 0
	MOVF        R8, 0 
	MOVWF       R0 
	MOVF        R9, 0 
	MOVWF       R1 
	MOVF        R10, 0 
	MOVWF       R2 
	MOVF        R11, 0 
	MOVWF       R3 
	MOVLW       10
	MOVWF       R4 
	MOVLW       0
	MOVWF       R5 
	MOVWF       R6 
	MOVWF       R7 
	CALL        _Div_32x32_U+0, 0
	MOVLW       48
	ADDWF       R0, 0 
	MOVWF       _digit+3 
;MyProject.c,60 :: 		LCD_Cmd(_LCD_CLEAR);
	MOVLW       1
	MOVWF       FARG_Lcd_Cmd_out_char+0 
	CALL        _Lcd_Cmd+0, 0
;MyProject.c,61 :: 		LCD_Out(1,3,"DISPLACEMENT");
	MOVLW       1
	MOVWF       FARG_Lcd_Out_row+0 
	MOVLW       3
	MOVWF       FARG_Lcd_Out_column+0 
	MOVLW       ?lstr5_MyProject+0
	MOVWF       FARG_Lcd_Out_text+0 
	MOVLW       hi_addr(?lstr5_MyProject+0)
	MOVWF       FARG_Lcd_Out_text+1 
	CALL        _Lcd_Out+0, 0
;MyProject.c,62 :: 		LCD_Out(2,5,digit);
	MOVLW       2
	MOVWF       FARG_Lcd_Out_row+0 
	MOVLW       5
	MOVWF       FARG_Lcd_Out_column+0 
	MOVLW       _digit+0
	MOVWF       FARG_Lcd_Out_text+0 
	MOVLW       hi_addr(_digit+0)
	MOVWF       FARG_Lcd_Out_text+1 
	CALL        _Lcd_Out+0, 0
;MyProject.c,65 :: 		Delay_ms(500);
	MOVLW       7
	MOVWF       R11, 0
	MOVLW       88
	MOVWF       R12, 0
	MOVLW       89
	MOVWF       R13, 0
L_main5:
	DECFSZ      R13, 1, 1
	BRA         L_main5
	DECFSZ      R12, 1, 1
	BRA         L_main5
	DECFSZ      R11, 1, 1
	BRA         L_main5
	NOP
	NOP
;MyProject.c,67 :: 		} while(1);
	GOTO        L_main2
;MyProject.c,68 :: 		}
L_end_main:
	GOTO        $+0
; end of _main

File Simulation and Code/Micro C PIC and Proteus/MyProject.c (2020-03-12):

// LCD module connections
sbit LCD_RS at RD4_bit;
sbit LCD_EN at RD5_bit;
sbit LCD_D4 at RD0_bit;
sbit LCD_D5 at RD1_bit;
sbit LCD_D6 at RD2_bit;
sbit LCD_D7 at RD3_bit;

sbit LCD_RS_Direction at TRISD4_bit;
sbit LCD_EN_Direction at TRISD5_bit;
sbit LCD_D4_Direction at TRISD0_bit;
sbit LCD_D5_Direction at TRISD1_bit;
sbit LCD_D6_Direction at TRISD2_bit;
sbit LCD_D7_Direction at TRISD3_bit;
// End LCD module connections






unsigned long temp;
unsigned int i;
char digit[]="0.00mm";

void main() {


TRISA=0xFF;


ADCON0=0x01;
ADCON1=0x0E;



     Lcd_Init();                        // Initialize LCD

  Lcd_Cmd(_LCD_CLEAR);               // Clear display
  Lcd_Cmd(_LCD_CURSOR_OFF);          // Cursor off
  LCD_Out(1,3,"PROJECT NAME");
  LCD_Out(2,5,"--LVDT--");
  Delay_ms(2000);
  Lcd_Cmd(_LCD_CLEAR);
  LCD_Out(1,8,"BY");
   LCD_Out(2,1,"3119  3122  3123");
   Delay_ms(2000);

  do {
    temp = ADC_Read(0);   // Get 10-bit results of AD conversion
    temp=temp*5000/1023;   //Convert ADC value to mV



    digit[0]=(temp/1000)+48;
    digit[2]=((temp%1000)/100)+48;
    digit[3]=(((temp%1000)%100)/10)+48;
    //digit[4]=(((temp%1000)%100)%10)+48;

    LCD_Cmd(_LCD_CLEAR);
    LCD_Out(1,3,"DISPLACEMENT");
    LCD_Out(2,5,digit);

    Delay_ms(500);

  } while(1);
}
